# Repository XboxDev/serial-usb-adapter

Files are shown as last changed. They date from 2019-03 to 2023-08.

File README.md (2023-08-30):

# Original Xbox Serial USB Adapter

This device allows for serial communication with an original Xbox and is primarily used for kernel debugging.

For questions or support, contact xbox7887 in the [XboxDev on Discord](https://discord.gg/WxJPPyz).

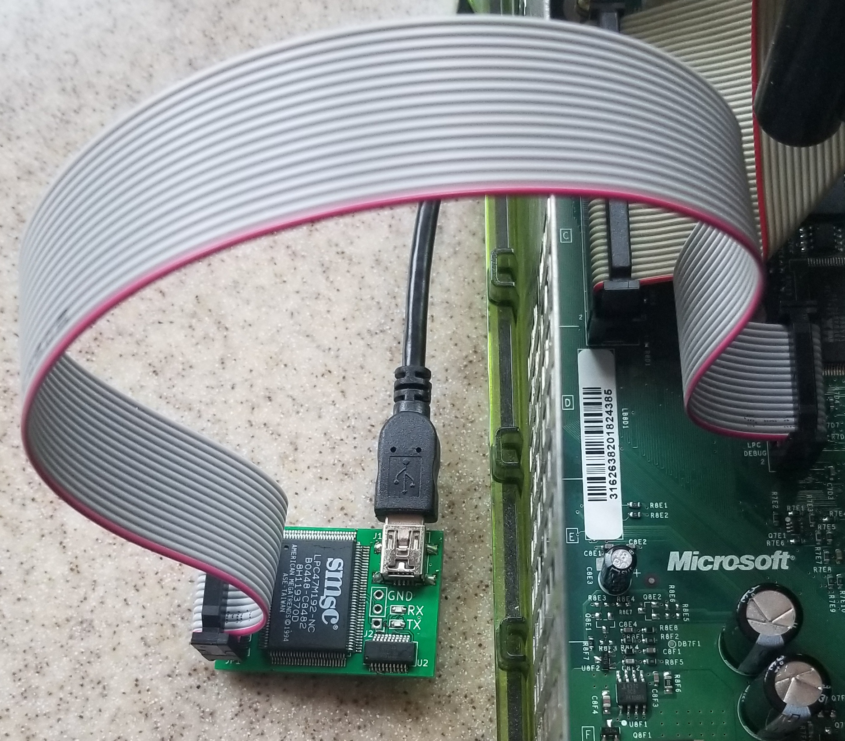
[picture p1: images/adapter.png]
Xbox Serial USB Adapter Image, REV A Xbox Serial USB Adapter, REV A


## Requirements

### Hardware

Any original Xbox of any version (although versions 1.3-1.5 require LFRAME# reconnect and version 1.6 requires full LPC port rebuild, including LFRAME#).
Debug and development kits will work without modification, however, retail boxes need to use a hacked kernel (X2 5035 or Cerbios for example) that initializes superio as well as have a 2x8 2.54mm pin header soldered to the LPC port.

### Software

A Windows OS capable of running WinDbg; versions 4.0.0018.0 (XDK) or [6.12.0002.633](http://download.microsoft.com/download/A/6/A/A6AC035D-DA3F-4F0C-ADA4-37C8E5D34E3D/setup/WinSDKDebuggingTools/dbg_x86.msi) have been tested successfully.

Optionally, [KiCad 7.0](http://kicad-pcb.org/download/) if you need to work with the PCB project files.

### BIOS Compatibility

   - Cerbios - use on any board
   - X2 4979 BFM - use on any board
   - X2 4981 (256 KB) - use on 1.2+ boards
   - X2 4983 BFM - use on any board
   - X2 5035 (512 KB) - use on 1.0-1.1 boards

## Usage

Connect a USB-C cable from your PC to the serial adapter, then the IDC cable ends into the serial adapter and Xbox LPC port pin headers respectively, ensuring the correct alignment and orientation as shown in the image above. **Incorrect orientation may result in damage to the adapter and/or your Xbox, you have been warned!**

Within WinDbg press `CTRL+K` to bring up the connection dialog and enter `115200` for the baud rate along with the `COM#` port as detected by your computer in device manager.

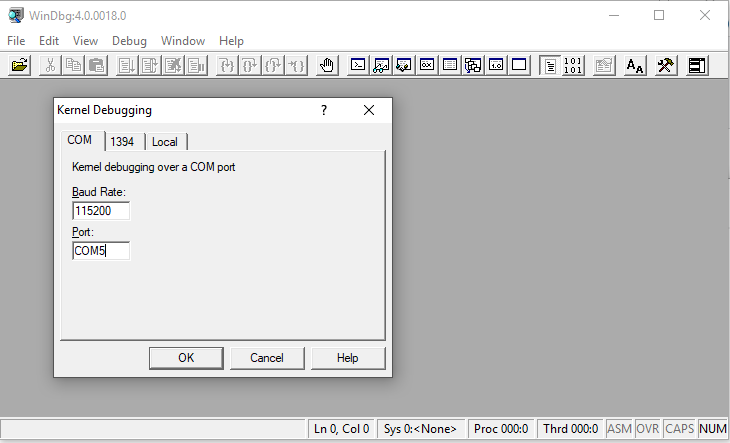
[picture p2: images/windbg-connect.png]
WinDbg Connection Image WinDbg Connection


`CTRL+Break` can be used to pause execution, `F5` to continue, and `F10/F11` to step over or through instructions.
`CTRL+ALT+D` will toggle verbose windbg protocol output for troubleshooting if needed.
The adapter's blue RX LED indicates signals sent from the PC and the green TX LED from the Xbox. 

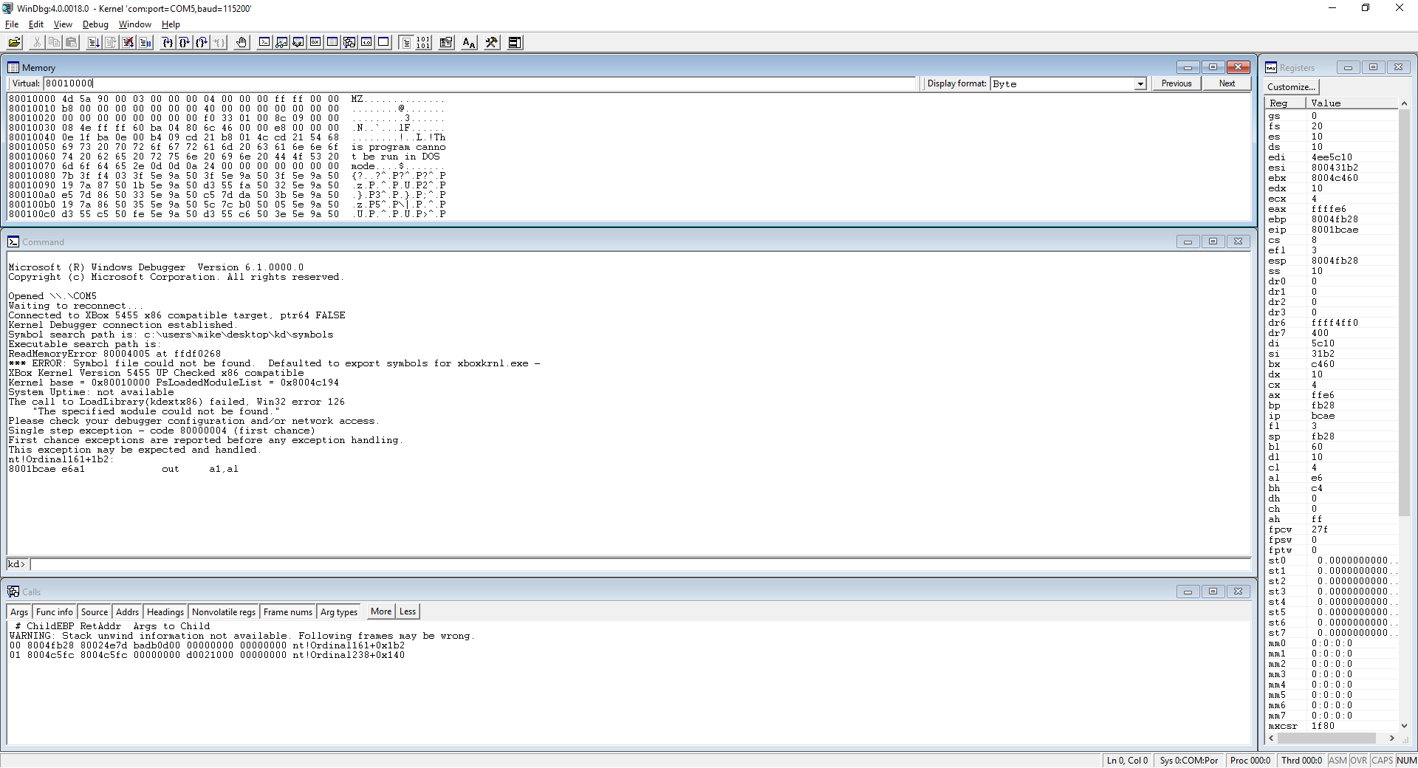
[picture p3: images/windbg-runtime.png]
WinDbg Runtime Image WinDbg Runtime


## Components

Bold designators are the bare minimum required for basic functionality but stability may be questionable. The entire UART to USB circuit and/or LED output is optional and can be replaced with an external 3.3V UART to USB cable jumpered to J2 instead.

| Count | Part/Value | Description | Designators | Notes |
| - | - | - | - | - |
| 1  | 2x8 2.54mm | Pin Header | **JP1** | |
| 1  | Stewart SS-52400-003 | USB-C Connector  | **J1** | |
| 1  | 1x3 2.54mm | Pin Header | J2 | Optional UART breakout |
| 1  | SG5032CAN | 14.318MHz 5032 Crystal Oscillator | **Y1** | |
| 1  | LPC47M192 | SuperIO | **U1** | The LPC47M157 is also compatible |
| 1  | FT231XS | UART to USB | **U2** | |
| 2  | 27R | 0603 SMD Resistor | **R1**, **R3** | Filtering |
| 2  | 10k | 0603 SMD Resistor | **R2**, **R4** | Configuration pull-ups/downs |
| 1  | 470R | 0603 SMD Resistor | R5 | LED power dissipation |
| 1  | 1.2k | 0603 SMD Resistor | R6 | LED power dissipation  |
| 2  | 5.1k | 0603 SMD Resistor | **R7**, **R8** | USB-C Configuration pull-downs |
| 2  | 100R | 4x0603 SMD Resistor Network | **RN1**, **RN2** | Terminating resistors for longer LPC ribbons (10+ inches) |
| 1  | 33 Ohm | 0603 Ferrite Bead | **FB1** | Filtering, can be substituted with a 0 ohm resistor or solder bridge |
| 3  | 47pF | 0603 SMD Capacitor | C6, C7 | Filtering |
| 6  | 10nF | 0603 SMD Capacitor | C3, **C8**, C9, **C10**, C12, C13 | Decoupling |
| 2  | 100nF | 0603 SMD Capacitor | C2, C11 | Decoupling |
| 1  | 4.7uF | 0603 SMD Capacitor | C1 | Bulk |
| 1  | 10uF | 0603 SMD Capacitor | C5 | Bulk |
| 1  | Green | 0603 SMD LED | D1 | |
| 1  | Blue | 0603 SMD LED | D2 | |

### External Components

| Count | Part/Value | Description | Designators | Notes |
| - | - | - | - | - |
| 1 | 2x8 2.54mm | Pin Header | N/A | Retail Xbox LPC Connector |
| 1 | 16 Wire 2.54mm | Female to Female IDC Ribbon Cable | N/A | Keep length under 18 inches for best results |
| 1 | USB-C Cable | Cable | N/A | |

### Component Retailers

* [Mouser](https://www.mouser.com/)
* [Digi-Key](https://www.digikey.com/)
* [Arrow](https://www.arrow.com/)
* [Utsource](https://www.utsource.net/)
* [AliExpress](https://www.aliexpress.com/)
* [JLCPCB](https://jlcpcb.com/)

## Reference

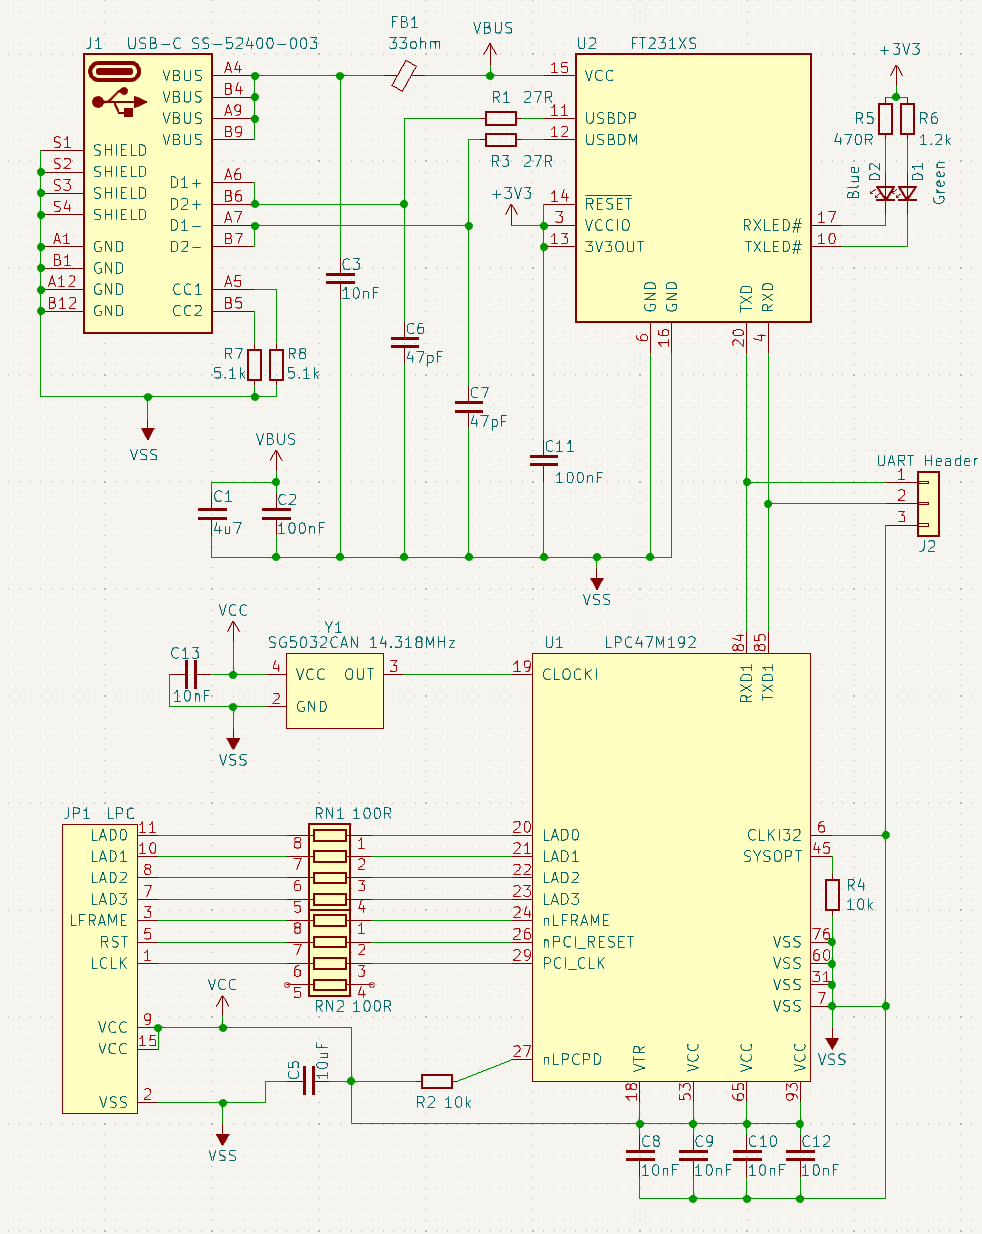
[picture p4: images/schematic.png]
Schematic Image Schematic Runtime


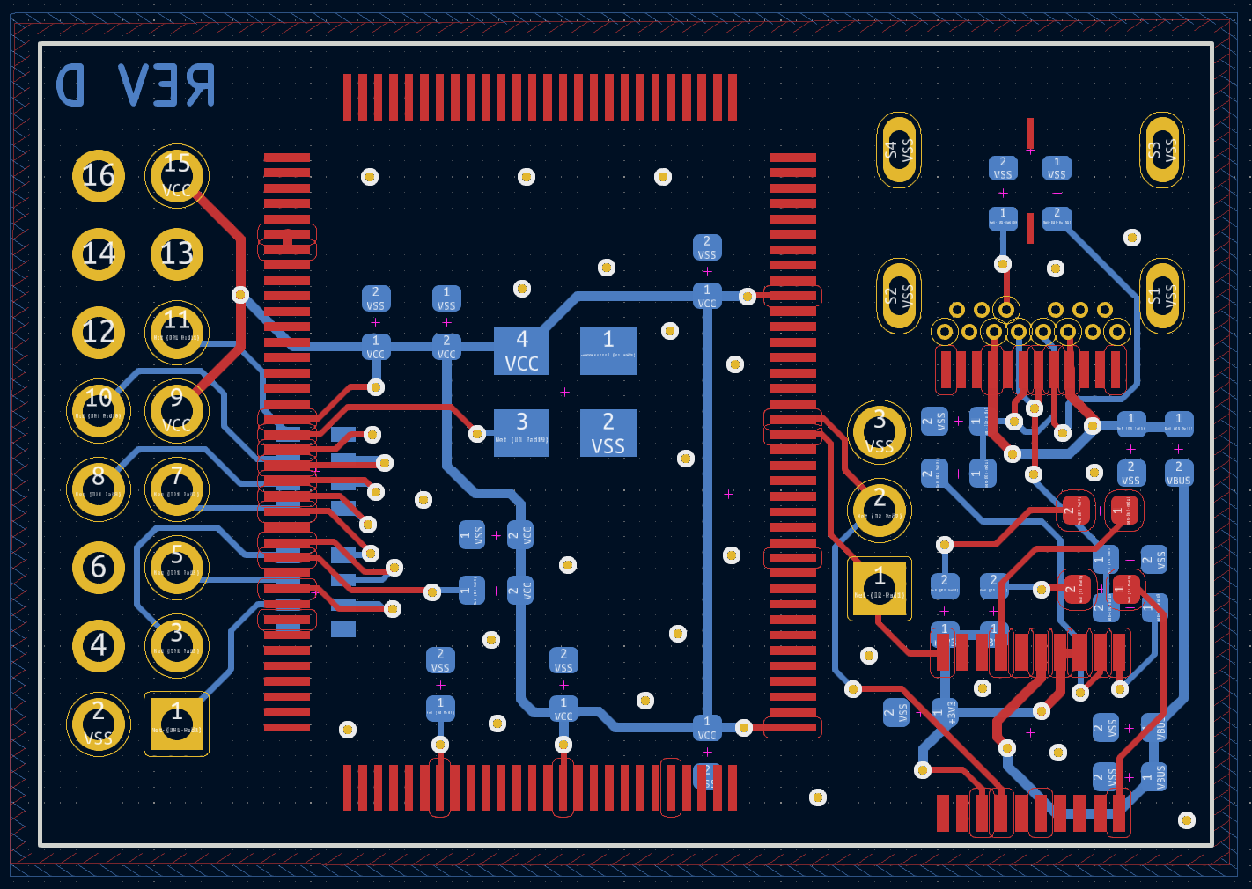
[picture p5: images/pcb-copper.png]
PCB Copper Image PCB Copper Runtime


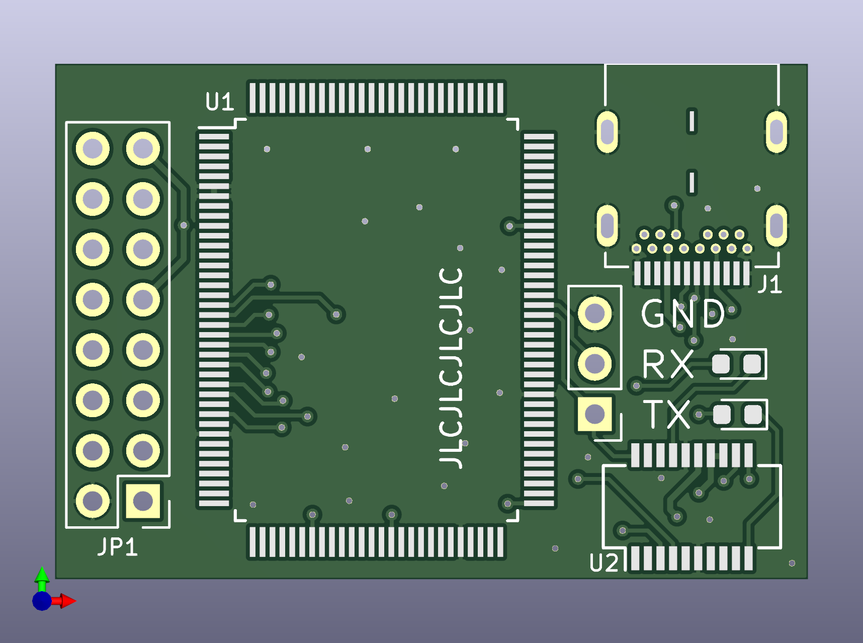
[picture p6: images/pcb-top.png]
PCB Top Image PCB Top Runtime


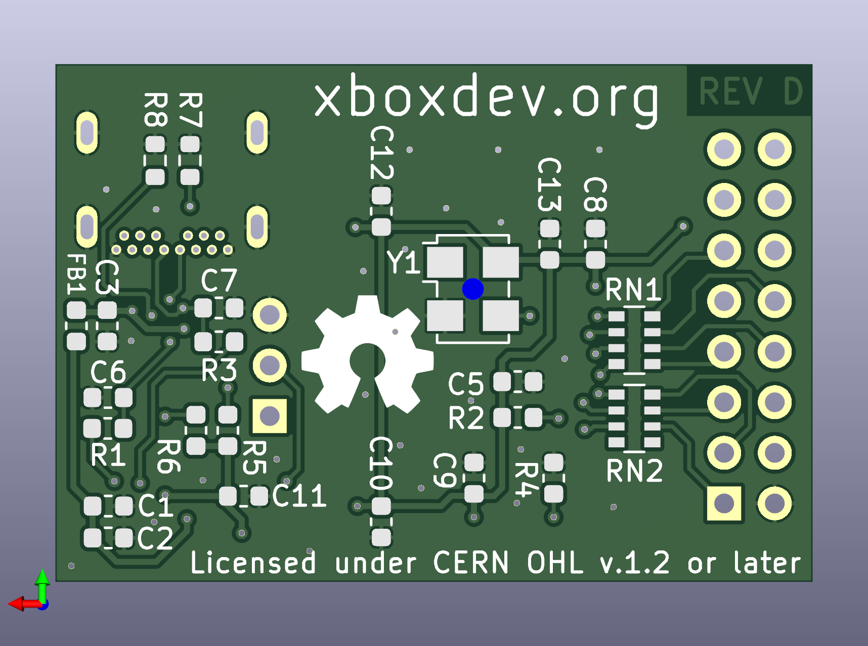
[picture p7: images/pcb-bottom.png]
PCB Bottom Image PCB Bottom Runtime


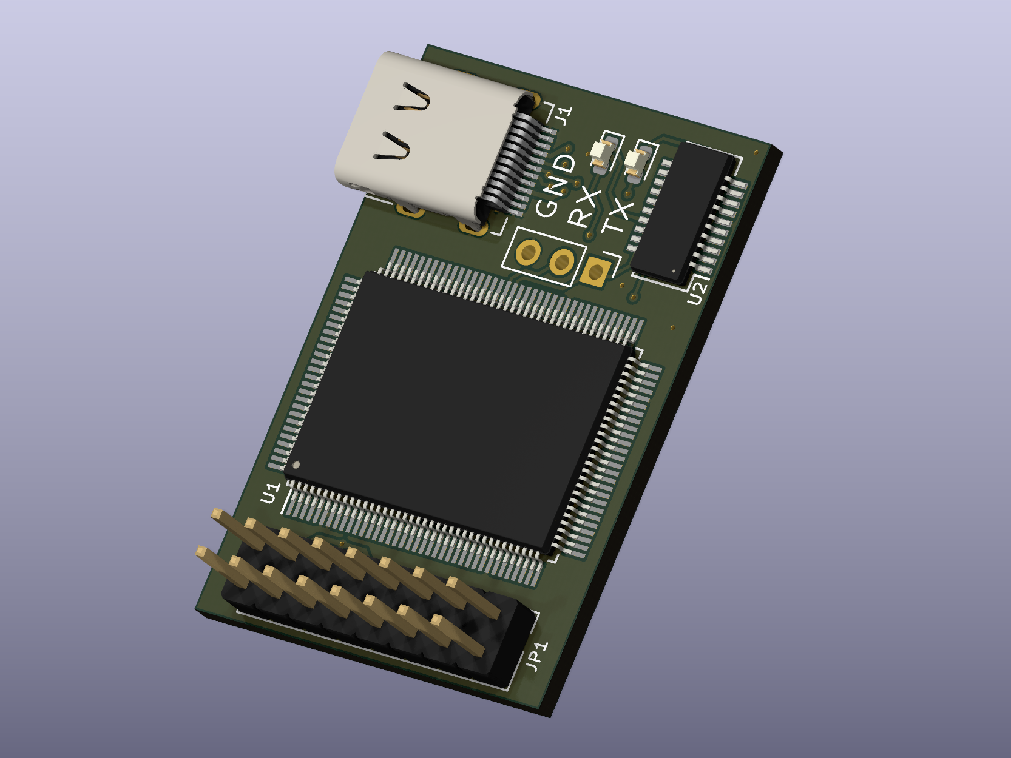
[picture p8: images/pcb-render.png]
PCB Render


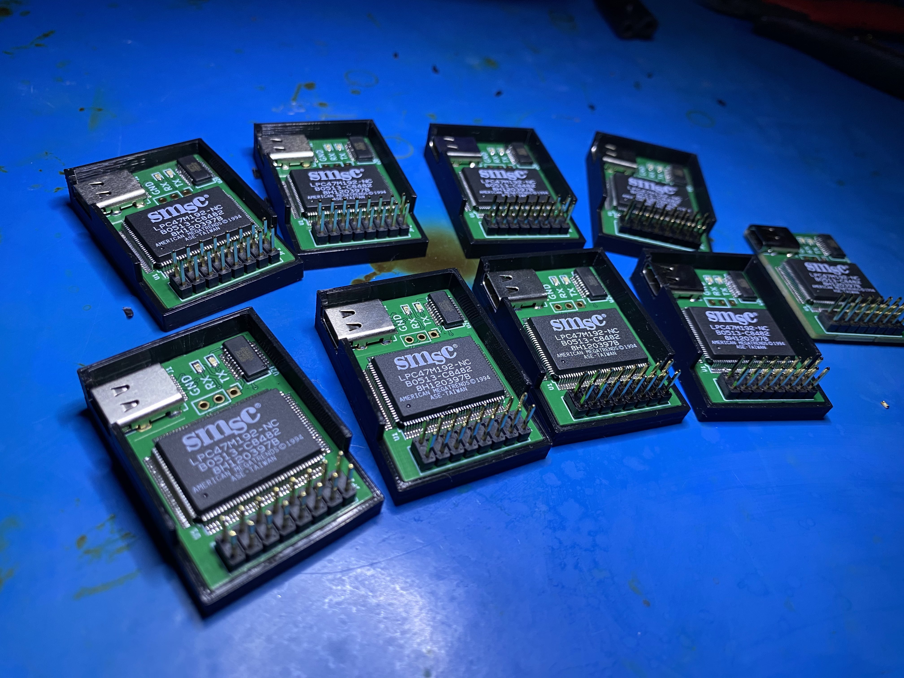
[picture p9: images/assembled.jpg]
Assembled PCBs


## Copyright

Copyright Mike Davis 2019.

This documentation describes Open Hardware and is licensed under the
CERN OHL v. 1.2 or later.

You may redistribute and modify this documentation under the terms of the
CERN OHL v.1.2 or later. (http://ohwr.org/cernohl). This documentation is distributed
WITHOUT ANY EXPRESS OR IMPLIED WARRANTY, INCLUDING OF
MERCHANTABILITY, SATISFACTORY QUALITY AND FITNESS FOR A
PARTICULAR PURPOSE. Please see the CERN OHL v.1.2 or later for applicable
conditions

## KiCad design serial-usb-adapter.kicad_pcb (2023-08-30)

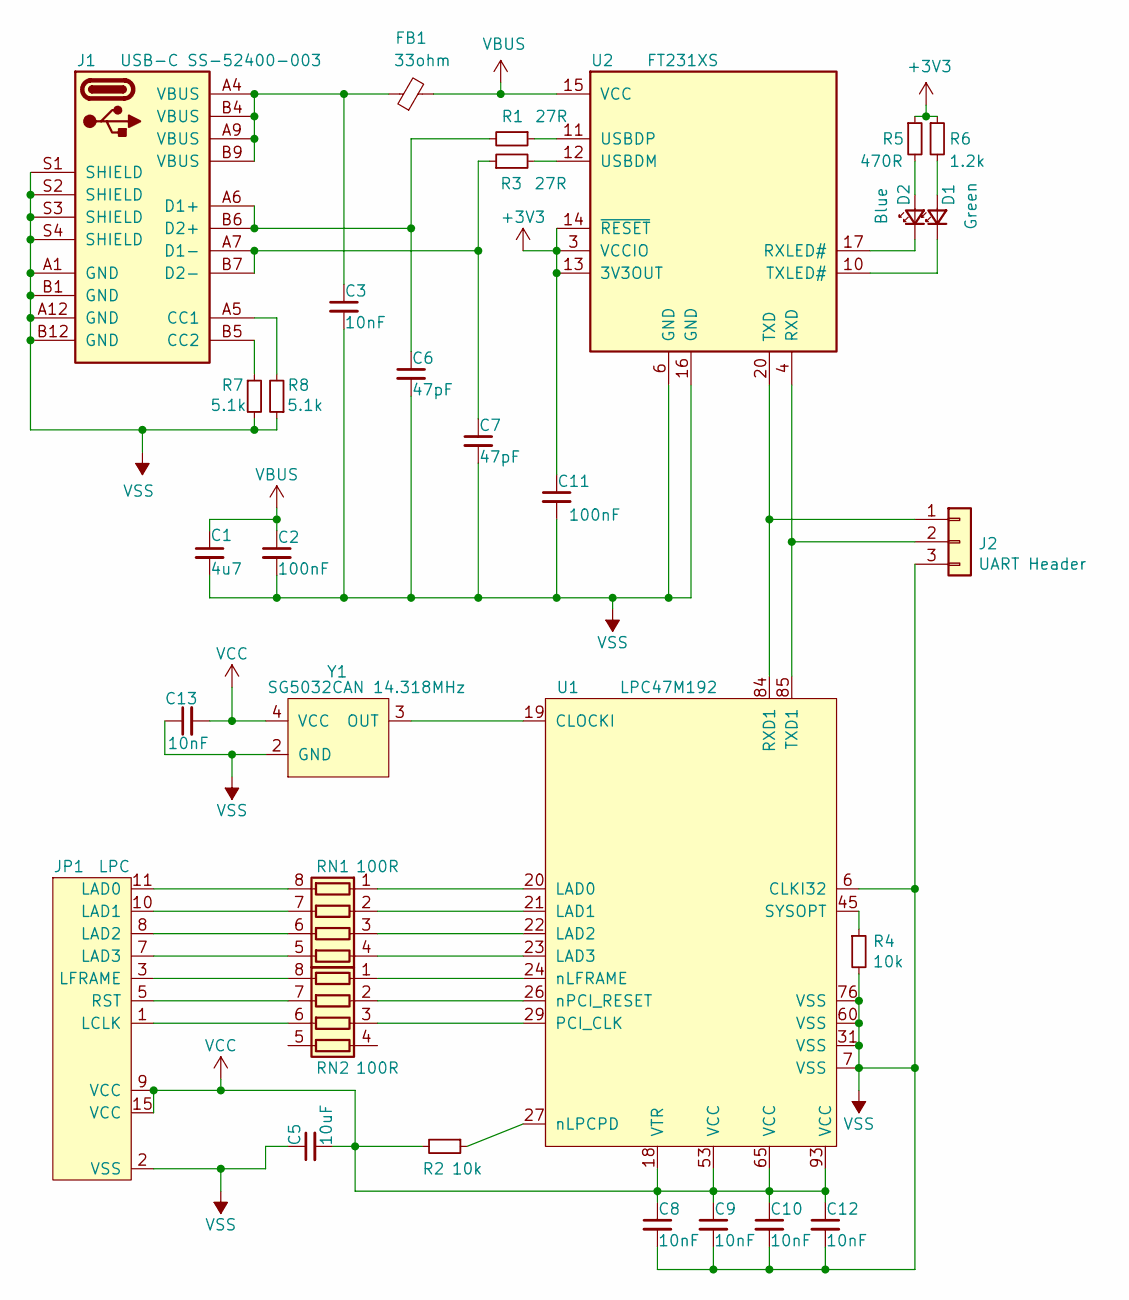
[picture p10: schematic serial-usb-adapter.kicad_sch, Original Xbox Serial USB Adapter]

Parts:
C1: 4u7; C_0603_1608Metric; LCSC C19666
C2, C11: 100nF; C_0603_1608Metric; LCSC C14663
C3, C8, C9, C10, C12, C13: 10nF; C_0603_1608Metric; LCSC C57112
C5: 10uF; C_0603_1608Metric; LCSC C19702
C6, C7: 47pF; C_0603_1608Metric; LCSC C1671
D1: Green; LED_0603_1608Metric; LCSC C72043
D2: Blue; LED_0603_1608Metric; LCSC C72041
FB1: 33ohm; L_0603_1608Metric; LCSC C88984
J1: USB-C SS-52400-003; SS-52400-003
J2: UART Header; PinHeader_1x03_P2.54mm_Vertical
JP1: LPC; PinHeader_2x08_P2.54mm_Vertical
R1, R3: 27R; R_0603_1608Metric; LCSC C25190
R2, R4: 10k; R_0603_1608Metric; LCSC C25804
R5: 470R; R_0603_1608Metric; LCSC C23179
R6: 1.2k; R_0603_1608Metric; LCSC C22765
R7, R8: 5.1k; R_0603_1608Metric; LCSC C25804
RN1, RN2: 100R; R_Array_Convex_4x0603; LCSC C79203
U1: LPC47M192; LQFP-128_14x20mm_P0.5mm
U2: FT231XS; SSOP-20_3.9x8.7mm_P0.635mm; LCSC C132160
Y1: SG5032CAN 14.318MHz; Oscillator_SMD_TXC_7C-4Pin_5.0x3.2mm_HandSoldering

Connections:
+3V3: C11.1, R5.1, R6.1, U2.3 (VCCIO), U2.13 (3V3OUT), U2.14 (~RESET)
unnamed: C3.1, FB1.1, J1.A4 (VBUS), J1.A9 (VBUS), J1.B4 (VBUS), J1.B9 (VBUS)
unnamed: C6.1, J1.A6 (D1+), J1.B6 (D2+), R1.2
unnamed: C7.1, J1.A7 (D1-), J1.B7 (D2-), R3.1
unnamed: D1.1 (K), U2.10 (TXLED#)
unnamed: D1.2 (A), R6.2
unnamed: D2.1 (K), U2.17 (RXLED#)
unnamed: D2.2 (A), R5.2
unnamed: J1.A5 (CC1), R8.2
unnamed: J1.B5 (CC2), R7.1
unnamed: J2.1 (TX), U1.84 (RXD1), U2.20 (TXD)
unnamed: J2.2 (RX), U1.85 (TXD1), U2.4 (RXD)
unnamed: JP1.1 (LCLK), RN2.6 (R3.2)
unnamed: JP1.3 (LFRAME), RN2.8 (R1.2)
unnamed: JP1.5 (RST), RN2.7 (R2.2)
unnamed: JP1.7 (LAD3), RN1.5 (R4.2)
unnamed: JP1.8 (LAD2), RN1.6 (R3.2)
unnamed: JP1.10 (LAD1), RN1.7 (R2.2)
unnamed: JP1.11 (LAD0), RN1.8 (R1.2)
unnamed: R1.1, U2.11 (USBDP)
unnamed: R2.1, U1.27 (nLPCPD)
unnamed: R3.2, U2.12 (USBDM)
unnamed: R4.1, U1.45 (SYSOPT)
unnamed: RN1.1 (R1.1), U1.20 (LAD0)
unnamed: RN1.2 (R2.1), U1.21 (LAD1)
unnamed: RN1.3 (R3.1), U1.22 (LAD2)
unnamed: RN1.4 (R4.1), U1.23 (LAD3)
unnamed: RN2.1 (R1.1), U1.24 (nLFRAME)
unnamed: RN2.2 (R2.1), U1.26 (nPCI_RESET)
unnamed: RN2.3 (R3.1), U1.29 (PCI_CLK)
unnamed: U1.19 (CLOCKI), Y1.3 (OUT)
VBUS: C1.1, C2.1, FB1.2, U2.15 (VCC)
VCC: C5.2, C8.1, C9.1, C10.1, C12.1, C13.2, JP1.9 (VCC), JP1.15 (VCC), R2.2, U1.18 (VTR), U1.53 (VCC), U1.65 (VCC), U1.93 (VCC), Y1.4 (VCC)
VSS: C1.2, C2.2, C3.2, C5.1, C6.2, C7.2, C8.2, C9.2, C10.2, C11.2, C12.2, C13.1, J1.A1 (GND), J1.A12 (GND), J1.B1 (GND), J1.B12 (GND), J1.S1 (SHIELD), J1.S2 (SHIELD), J1.S3 (SHIELD), J1.S4 (SHIELD), J2.3 (GND), JP1.2 (VSS), R4.2, R7.2, R8.1, U1.6 (CLKI32), U1.7 (VSS), U1.31 (VSS), U1.60 (VSS), U1.76 (VSS), U2.6 (GND), U2.16 (GND), Y1.2 (GND)

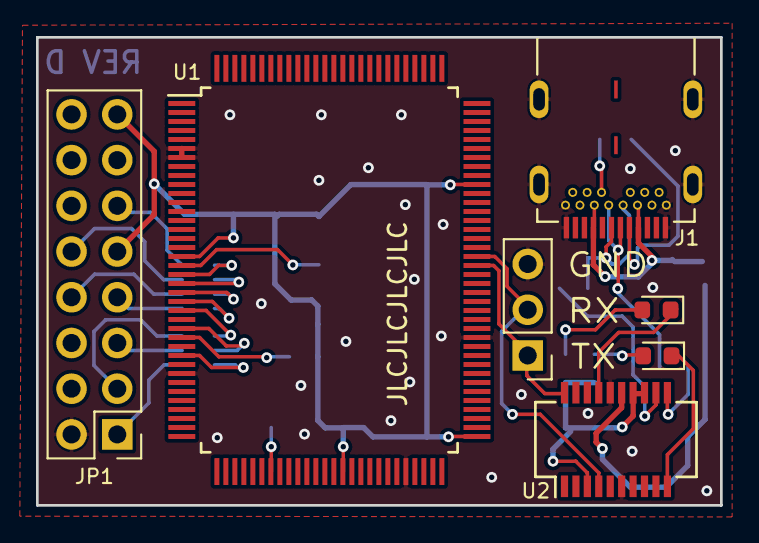
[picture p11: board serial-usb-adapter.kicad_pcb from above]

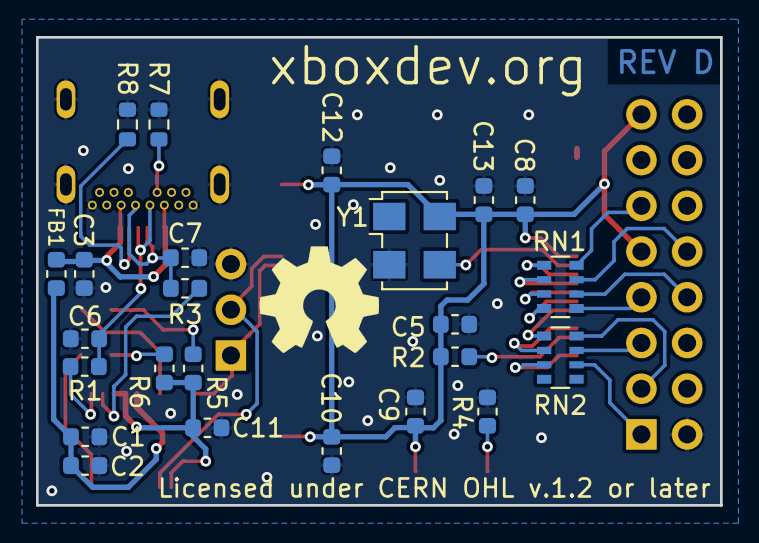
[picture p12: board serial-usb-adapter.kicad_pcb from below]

Board: 2 copper layers, 38.0 x 26.0 mm, 31 parts (24 on the bottom side), 34 nets.

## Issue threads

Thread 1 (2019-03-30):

Pre-Assembled Unit Interest

Ernegien, 2019-03-30:
I've made 20 of these adapters (includes all cables and pin-header for the Xbox LPC) and will be selling them to active XboxDev contributors for $15 USD plus shipping. Non-contributor pricing is $30 USD plus shipping. This will be a bit different however in that those who benefit the most from it will be given priority over others at my discretion so I'd like to get an idea of who's interested first as once they're gone I likely won't be making another batch.

**Note, as described in the README, you'll need either a debug/devkit or a retail v1.0-1.2 motherboard with the capability of soldering a pin-header onto it in order to use this.**

Please let me know via here or Discord if you're interested and whether or not you're located in the EU so I have an idea of how many to ship in bulk there for further distribution.

kaosengr, 2019-03-30:
I'm interested in obtaining at least 1, 2 if possible.

dans34, 2019-04-01:
I would be interested in one

Closed 2023-08-30.

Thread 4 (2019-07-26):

TODO's

Ernegien, 2019-07-26:
So I don't forget...

1. Re-generate PCB screenshots and gerbers; no need to update the hardware revision as there were just minor silkscreen changes for interchangeable parts.

2. Fix screenshot tooltip copypaste mistakes.

3. Clarify that iND kernels don't fully initialize KD (still need to test if plain serial output works however). If not using a debug/devkit, the following hacked kernels have been tested successfully with KD and windbg:

   - X2 4979 BFM - use on any board
   - X2 4981 (256 KB) - use on 1.2+ boards
   - X2 4983 BFM - use on any board
   - X2 5035 (512 KB) - use on 1.0-1.1 boards

Closed 2023-08-30.

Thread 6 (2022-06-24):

Serial USB adapter becomes erratic when ribbon cable exceeds 10 inches

gaasedelen, 2022-06-24:
As the ribbon cable exceeds ~10 inches, the Serial USB adapter begins to behave erratically. This manifests in several different ways including:

- Xbox may outright FRAG when the serial adapter is attached
- WinDbg can hang, presumably waiting retrying a request for data while the SMSC keeps outputting invalid/garbage data
    - the TX (green) LED can be seen going nuts as retry attempts are made by the xbox to send the requested data
- The Xbox will not respond to any break's sent by WinDbg, so a debug session never connects.
    - RX (blue) LED blinks, but presumably the signals sent from the SMSC chip down the ribbon to the Xbox are getting corrupted / mangled by the time they reach the mobo
 - Past ~11 inches ribbon length I have never been able to successfully established a debug session

It seems like there's a signal integrity issue and was hoping someone who is an EE might be able to help diagnose what could be going wrong here.

I'm pretty confident that by the time the signals reach our SMSC chip after running along the ribbon, they're too muddy for it to decode correctly.

Some additional thoughts:
- DVT4's have longer than 10 inch ribbons running to their serial boards
- I tried cutting SDA/SCL out of the ribbon close to the LPC side see if that might help reduce 'noise' on the ribbon
   - The ribbons in DVT4's also cut these two lines, which is why I decided to try it but it didn't help
- Is there anything that we missed about the design of the native DVT4 serial board that should be ported over to this?
- Are there going to be any issues with the fact that the FTDI side of our Serial USB circuit is powered by USB while the SMSC side is powered by the Xbox LPC? Is this best practice, or something that could also get refined in a new revision?
- This issue manifests at least on all REV A and REV C boards that I have on hand (and presumably REV B too)
- C4 is removed on all these boards. Anytime I have C4 on one of the boards, The Xbox outright FRAGs

 I chatted briefly with a non-Xbox EE friend who had the following to say:

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

Would be more than happy to hear any other thoughts from HW / EE / CSE people

gaasedelen, 2022-10-11:
I just wanted to follow up and confirm that I integrated these changes to improve signal quality into a new board revision.

I removed C4, added terminating resistor networks/arrays for the LPC signal lines, and switched the board over to use a USB-C port as that's where everything is heading anyways. If you don't intend to use the board at the end of a ribbon, you should be able to just jump each of the connections instead of placing resistor networks.

Still in the process of vetting my changes but the board now works great at longer ribbon lengths.

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

I'm kind of a KiCad noob and may have muddied up the project files a bit (like project symbol/footprint/model libraries, paths) so I'd like to try and clean it up before making a PR. If anyone wants the gerbers/bom/centroid files before then I'd be happy to share them.

Closed 2023-08-30.

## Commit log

2019-03-30 Initial Rev B commit
    [serial-usb-adapter.kicad_pcb, serial-usb-adapter.sch]
2019-06-26 Pin header pitch correction in README.md
2019-07-25 pin pitch & resistor value correction
2019-07-25 swap silkscreen positions of R1 & R3
    [serial-usb-adapter.kicad_pcb]
2022-04-04 Replace Mini USB connector with Micro USB
    [serial-usb-adapter.kicad_pcb, serial-usb-adapter.kicad_sch, serial-usb-adapter.sch]
2023-08-13 Adds USB-C based Xbox Serial USB Adapter (Rev D)
    [serial-usb-adapter.kicad_pcb, serial-usb-adapter.kicad_sch]

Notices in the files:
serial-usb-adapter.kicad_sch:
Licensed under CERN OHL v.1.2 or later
